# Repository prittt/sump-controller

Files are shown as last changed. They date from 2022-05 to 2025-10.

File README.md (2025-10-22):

# Sump Controller

An basic IoT project to monitor and control the water level in a collecting sump using ESP8266 NodeMCU with email notifications and visual/audio alerts.

<p align="center">
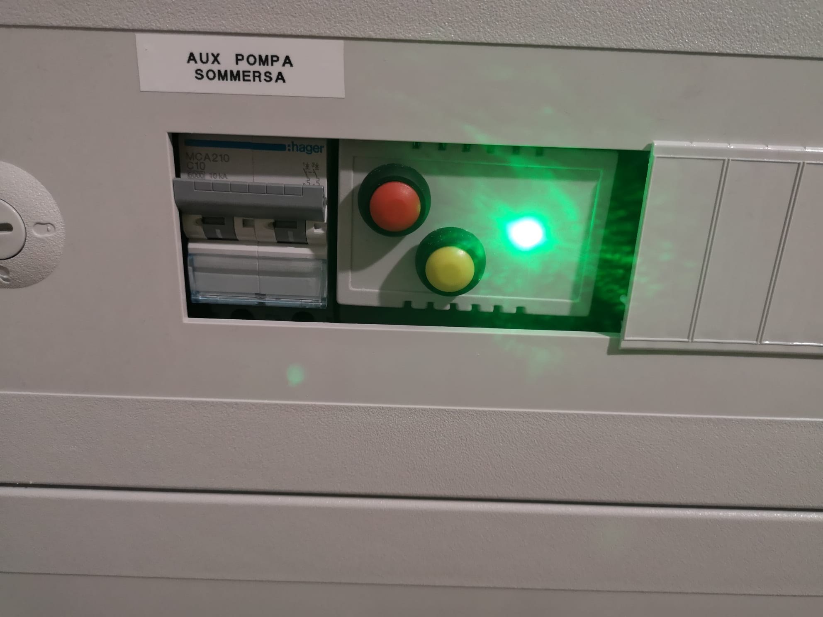
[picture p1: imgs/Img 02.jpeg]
  
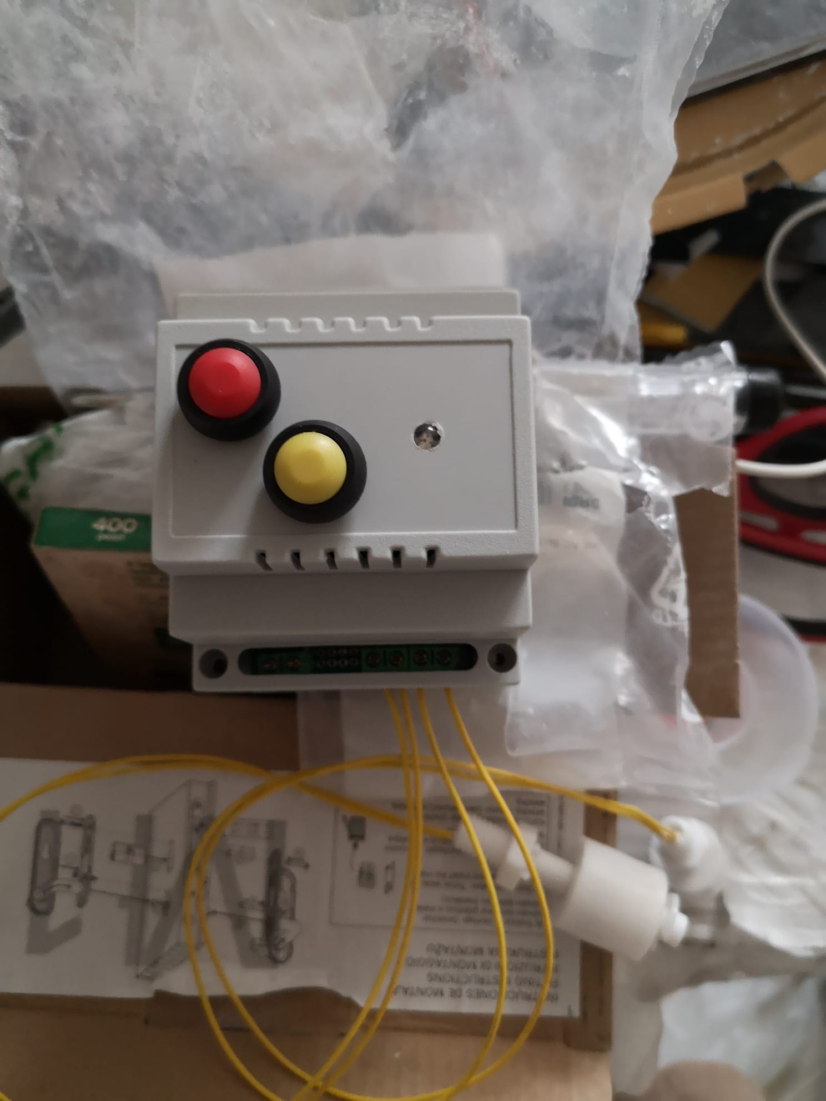
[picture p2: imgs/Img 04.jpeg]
  
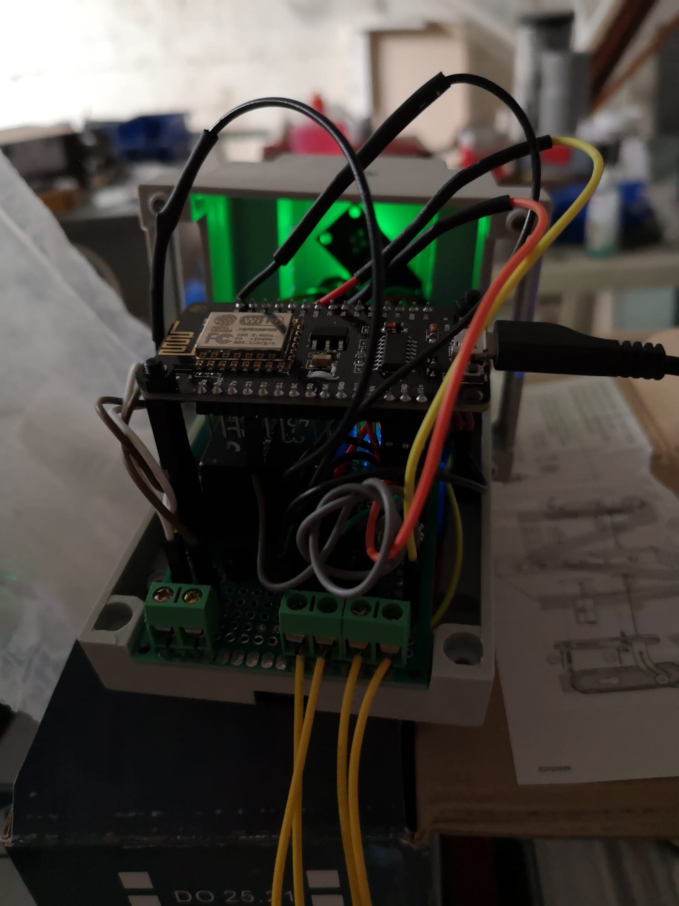
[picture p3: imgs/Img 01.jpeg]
  
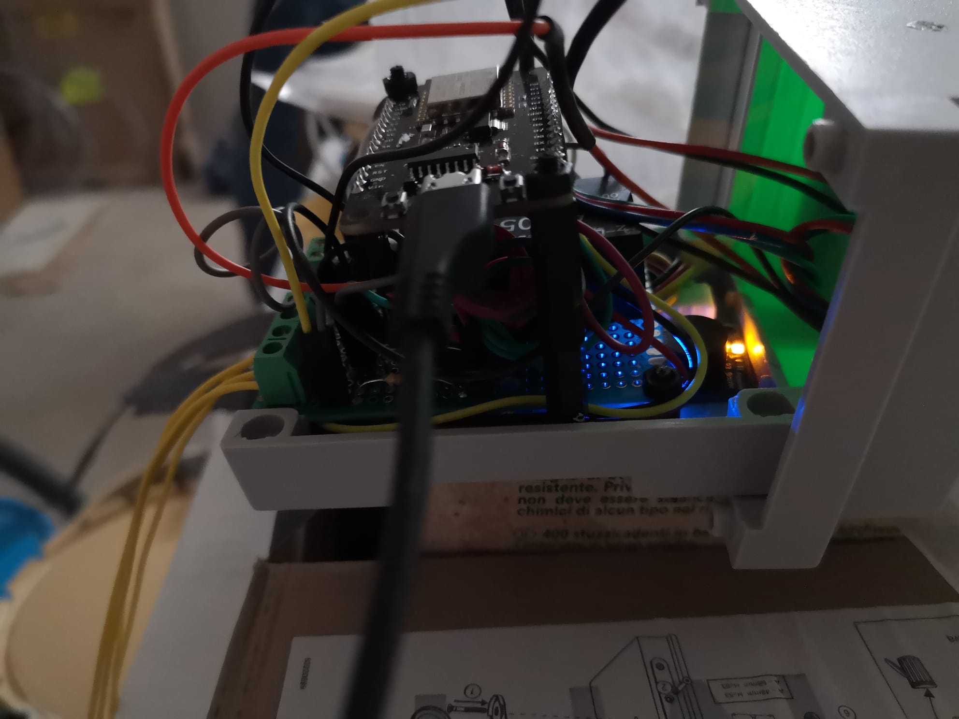
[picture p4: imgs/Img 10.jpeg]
  
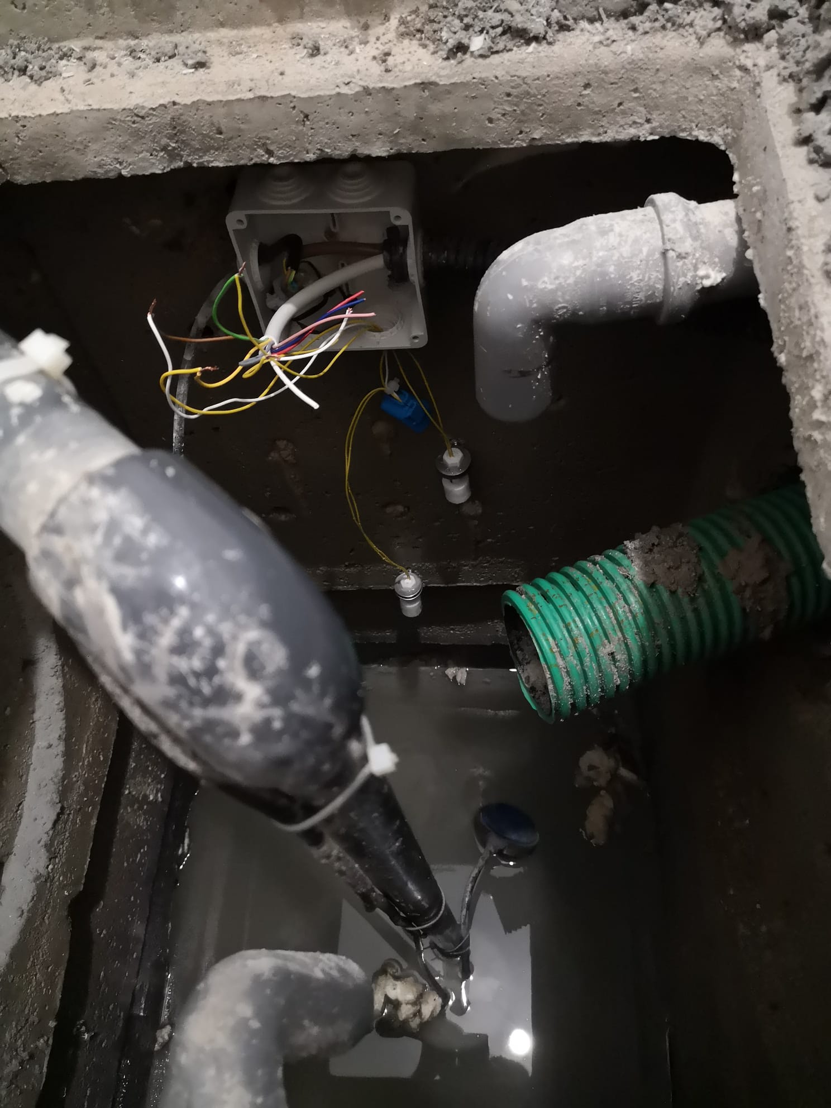
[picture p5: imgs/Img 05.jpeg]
  
</p>

## Overview

This project implements a smart water level monitoring system for sump pumps or water collection basins. The system uses two float switches to detect water levels and provides real-time notifications via email, visual LED indicators, and an audible alarm. The ESP8266 NodeMCU connects to WiFi to send status updates to multiple recipients.

## Features

- **Dual Water Level Detection**: Uses two float switches (low and high) to monitor water levels
- **Email Notifications**: Sends automatic email alerts via Gmail SMTP for different water level conditions:
  - Critical: High water level reached
  - Warning: Low water level reached
  - Restoring: High float deactivated but low float still submerged
  - OK: System returned to normal
  - Weekly checkup: Automatic status email every week
- **Visual Indicators**: RGB LED provides color-coded status:
  - 🟢 Green: Normal operation
  - 🔵 Blue: Warning state
  - 🔴 Red: Critical state
- **Audio Alert**: Buzzer alarm for abnormal water levels with manual disable option
- **Alarm Control**: Additional button to temporarily disable/enable the audio alarm
- **Watchdog Protection**: Prevents ESP8266 crashes during operation

## Hardware Requirements

- ESP8266 NodeMCU development board
- 2x Float switches (low and high water level)
- RGB LED module (common cathode)
- Passive buzzer
- Push button (for alarm control)
- Connecting wires
- Power supply (5V USB or appropriate power source)

## Pin Configuration

| Component | GPIO Pin | NodeMCU Pin |
|---|---|---|
| Low Float Switch | GPIO 12 | D6 |
| High Float Switch | GPIO 13 | D7 |
| Buzzer | GPIO 14 | D5 |
| Red LED | GPIO 5 | D1 |
| Blue LED | GPIO 4 | D2 |
| Green LED | GPIO 16 | D0 |
| Additional Button | GPIO 10 | SD3 |

## Circuit Diagram

The Fritzing schematic is available in the `fritzing/` folder. Additional custom modules used in the design:
- ESP8266 NodeMCU module
- Passive Buzzer module
- RGB Full Color LED module

## Software Dependencies

### Arduino Libraries Required

1. **ESP8266WiFi** - WiFi connectivity for ESP8266
2. **ESP_Mail_Client** - For sending emails via SMTP
3. **aplayer** - Arduino Buzzer Player library from [https://github.com/prittt/ArduinoBuzzerPlayer](https://github.com/prittt/ArduinoBuzzerPlayer)

### Installation

Install the required libraries through the Arduino IDE Library Manager or manually download them from their respective repositories.

## Configuration

### 1. Arduino IDE Setup for ESP8266

Follow the instructions here to enable programming of ESP8266 NodeMCU with Arduino IDE:
[Setting Up the Arduino IDE to Program ESP8266](https://www.instructables.com/Setting-Up-the-Arduino-IDE-to-Program-ESP8266/)

### 2. WiFi Configuration

Edit the following lines in `code/code.ino`:

```cpp
#define WIFI_SSID "your_wifi_ssid"
#define WIFI_PASSWORD "your_wifi_password"
```

### 3. Email Configuration

Configure your Gmail account for SMTP:

```cpp
#define AUTHOR_EMAIL "your_email@gmail.com"
#define AUTHOR_PASSWORD "your_app_password"
```

**Important**: Use an [App Password](https://support.google.com/accounts/answer/185833) instead of your regular Gmail password for security.

Add recipient emails and names:

```cpp
String emails[] = {"recipient1@example.com", "recipient2@example.com"};
size_t emails_size = sizeof(emails)/sizeof(String);
String names[]  = {"Name1", "Name2"};
```

### 4. Timing Configuration

Adjust the following constants as needed:

```cpp
#define STATUS_EMAIL_INTERVAL 604800000  // Weekly status email (in milliseconds)
#define WIFI_CONNECTION_TIMEOUT 15000    // WiFi connection timeout (15 seconds)
#define LOOP_DELAY_NORMAL_MODE 10000     // Normal mode delay (10 seconds)
#define LOOP_DELAY_PROBLEM_MODE 10000    // Problem mode delay (10 seconds)
```

## System States

The system operates in four different states:

1. **FINE (Green LED)**: Both float switches are inactive, water level is normal
2. **WARNING (Blue LED)**: Low float switch is activated, water level is rising
3. **WARNING_RESTORING (Blue LED)**: High float switch deactivated but low float still active
4. **CRITICAL (Red LED)**: High float switch is activated, water level is dangerously high

## Operation

### Normal Operation

1. When powered on, the system connects to WiFi and initializes (Green LED)
2. Continuously monitors both float switches
3. Sends a status email every week to confirm the system is running
4. Changes state and sends notifications when water level changes

### Alarm Control

- Press the additional button briefly to toggle the audio alarm on/off
- When disabled: LED blinks red 3 times
- When enabled: LED blinks green 3 times
- The visual LED status indicator remains active regardless of alarm state

### Email Notifications

The system sends emails for the following events:
- **CRITICAL**: High float switch triggered
- **WARNING**: Low float switch triggered
- **RESTORING?**: Transitioning from critical to warning state
- **OK**: System returned to normal
- **CHECKUP**: Weekly status confirmation (sent every 7 days)

## Debug Mode

To enable serial debug output, set:

```cpp
#define DEBUG true
```

This will print detailed status information to the Serial Monitor at 115200 baud.

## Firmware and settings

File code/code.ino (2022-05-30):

#include <aplayer.h> // Code from https://github.com/prittt/ArduinoBuzzerPlayer

#define DEBUG false

#include <Arduino.h>
#include <aplayer.h>

#if defined(ESP32)
  #include <WiFi.h>
#elif defined(ESP8266)
  #include <ESP8266WiFi.h>
#endif
#include <ESP_Mail_Client.h>

//#define WIFI_SSID "HUAWEI P20"
//#define WIFI_PASSWORD "123456789"
#define WIFI_SSID "welcometothejungle"
#define WIFI_PASSWORD "W!ldB&&r52"

#define SMTP_HOST "smtp.gmail.com"
#define SMTP_PORT 465

/* The sign in credentials */
#define AUTHOR_EMAIL "pozzetto.firenze@gmail.com"
#define AUTHOR_PASSWORD "ibqjxrdfflnfwngy"

/* Recipient's emails and names*/
String emails[] = {"federico.bolelli@unimore.it", "elena.bega.mo@gmail.com"};
size_t emails_size = sizeof(emails)/sizeof(String);
String names[]  = {"Federico", "Elena"};

#define FLOATINGLOW_PIN   12 // Pin connected to the lower floating
#define FLOATINGHIGHT_PIN 13 // Pin connected to the higher floating
#define BUZZER_PIN        14 // Pin which control the buzzer
APlayer myPlayer(BUZZER_PIN); // Create a player object specifying the buzzer's pin

#define GREENLED_PIN 16 // Pin to control green LED
#define REDLED_PIN    5 // Pin to control red LED
#define BLUELED_PIN   4 // Pin to control yellow LED

#define STATUS_EMAIL_INTERVAL 604800000 // One week
unsigned long int last_email_sent = millis() - STATUS_EMAIL_INTERVAL; // This is to ensure that the email will be sent at startup

#define WIFI_CONNECTION_TIMEOUT 15000  // 15s // 30000 // 30s
#define LOOP_DELAY_NORMAL_MODE  10000  // 10s // 300000 // 5m
#define LOOP_DELAY_PROBLEM_MODE 10000  // 10s 

#define ADDITIONAL_BUTTON 10

/* The SMTP Session object used for Email sending */
SMTPSession smtp;

// Butto press function with "debouncing"
# define BUTTONS_PRESS_TIME_SHORT 1000
# define BUTTONS_PRESS_TIME_LONG 3000
bool IsPressed(int button_pin, unsigned long press_duration = BUTTONS_PRESS_TIME_SHORT, bool direct = 1){
    
    if (!direct){
        if(digitalRead(button_pin) == LOW){
          unsigned long start_press = millis();
          while(digitalRead(button_pin) == LOW && (millis() - start_press < press_duration)){wdt_reset();} // The reset on the ESP8266 must be fast (watchdog max-time is quite small). The call to wdt_reset() is to avoid the random crash of the module!
  
          if(digitalRead(button_pin) == LOW && (millis() - start_press >= press_duration)){
            return true;  
          }
        }
    }else{
        if(digitalRead(button_pin) == HIGH){
          unsigned long start_press = millis();
          while(digitalRead(button_pin) == HIGH && (millis() - start_press < press_duration)){wdt_reset();} // The reset on the ESP8266 must be fast (watchdog max-time is quite small). The call to wdt_reset() is to avoid the random crash of the module!
  
          if(digitalRead(button_pin) == HIGH && (millis() - start_press >= press_duration)){
            return true;  
          }
        }
    }
    
    return false;
}

/* Callback function to get the Email sending status */
void smtpCallback(SMTP_Status status);

bool ConnectToWifiAndSendEmail(String floating_status, String email_content){
  if (DEBUG){
    Serial.println();
    Serial.print("Connecting to AP");
  }
  
  WiFi.begin(WIFI_SSID, WIFI_PASSWORD);
  unsigned long connection_start = millis();
  while (WiFi.status() != WL_CONNECTED){
    if (millis() - connection_start > WIFI_CONNECTION_TIMEOUT) {

        if (DEBUG){
          Serial.println("Unable to connect to the WiFi, skipping");
        }
      return false;  
    }
    
    if (DEBUG){
      Serial.print(".");
    }
    delay(200);
  }

  if (DEBUG){
    Serial.println("");
    Serial.println("WiFi connected.");
    Serial.println("IP address: ");
    Serial.println(WiFi.localIP());
    Serial.println();
  }
  
  /** Enable the debug via Serial port
   * none debug or 0
   * basic debug or 1
  */
  smtp.debug(DEBUG);

  /* Set the callback function to get the sending results */
  smtp.callback(smtpCallback);

  /* Declare the session config data */
  ESP_Mail_Session session;

  /* Set the session config */
  session.server.host_name = SMTP_HOST;
  session.server.port = SMTP_PORT;
  session.login.email = AUTHOR_EMAIL;
  session.login.password = AUTHOR_PASSWORD;
  session.login.user_domain = "";

  /* Declare the message class */
  SMTP_Message message;

  /* Set the message headers */
  message.sender.name = "Pozzetto Via Firenze";
  message.sender.email = AUTHOR_EMAIL;
  message.subject = floating_status;

  for (size_t i = 0; i < emails_size; ++i) {
    message.addRecipient(names[i], emails[i]);
  }

  /*Send HTML message*/
  String htmlMsg = "<h1>" + email_content + "</h1><p>Sent from ESP board</p>";
  message.html.content = htmlMsg.c_str();
  message.html.content = htmlMsg.c_str();
  message.text.charSet = "us-ascii";
  message.html.transfer_encoding = Content_Transfer_Encoding::enc_7bit;

  /*
  //Send raw text message
  String textMsg = "Hello World! - Sent from ESP board";
  message.text.content = textMsg.c_str();
  message.text.charSet = "us-ascii";
  message.text.transfer_encoding = Content_Transfer_Encoding::enc_7bit;
  
  message.priority = esp_mail_smtp_priority::esp_mail_smtp_priority_low;
  message.response.notify = esp_mail_smtp_notify_success | esp_mail_smtp_notify_failure | esp_mail_smtp_notify_delay;*/

  /* Set the custom message header */
  //message.addHeader("Message-ID: <abcde.fghij@gmail.com>");

  /* Connect to server with the session config */
  if (!smtp.connect(&session)){
    return false;
  }

  /* Start sending Email and close the session */
  if (!MailClient.sendMail(&smtp, &message)){
    return false;
    if (DEBUG){ 
      Serial.println("Error sending Email, " + smtp.errorReason());
    }
  }
  return true;
}

void SetBlue(){
  analogWrite(BLUELED_PIN , 255);
  analogWrite(REDLED_PIN  , 0);
  analogWrite(GREENLED_PIN, 0);   
}

void SetRed(){
  analogWrite(BLUELED_PIN , 0);
  analogWrite(REDLED_PIN  , 255);
  analogWrite(GREENLED_PIN, 0);   
}

void SetGreen(){
  analogWrite(BLUELED_PIN , 0);
  analogWrite(REDLED_PIN  , 0);
  analogWrite(GREENLED_PIN, 255);   
}

void setup(){
  pinMode(FLOATINGLOW_PIN  , INPUT);
  pinMode(FLOATINGHIGHT_PIN, INPUT);

  pinMode(ADDITIONAL_BUTTON, INPUT);

  pinMode(BLUELED_PIN, OUTPUT);
  pinMode(REDLED_PIN , OUTPUT);
  pinMode(BLUELED_PIN, OUTPUT);

  SetGreen();

  if (DEBUG){
    Serial.begin(115200);
  }
}

enum system_status {
  FINE = 0, 
  WARNING = 1,
  WARNING_RESTORING = 2,
  CRITICAL = 3
};

int current_status = FINE;
int last_email_succesfully_sent = true;

void SetOff() {
  analogWrite(BLUELED_PIN , 0);
  analogWrite(REDLED_PIN  , 0);
  analogWrite(GREENLED_PIN, 0);   
}

void BlinkRed(int n = 3, int freq = 100) {
  for (int i = 0; i < n; ++i) {
    SetRed();
    delay(freq);
    SetOff();
    delay(freq);  
  }
}

void BlinkGreen(int n = 3, int freq = 100) {
  for (int i = 0; i < n; ++i) {
    SetGreen();
    delay(freq);
    SetOff();
    delay(freq);  
  }
}

bool alarm_disabled = false;

void loop(){

  bool hight_floating_pressed = IsPressed(FLOATINGHIGHT_PIN);
  bool   low_floating_pressed = IsPressed(FLOATINGLOW_PIN);
  bool   additional_button    = IsPressed(ADDITIONAL_BUTTON, BUTTONS_PRESS_TIME_SHORT, 0);

  if (DEBUG) {
    Serial.println("");
    Serial.print("hight_floating_pressed = "); hight_floating_pressed ? Serial.println("true") : Serial.println("false");
    Serial.print("low_floating_pressed = ");   low_floating_pressed   ? Serial.println("true") : Serial.println("false");
    Serial.print("additional_button = ");      additional_button      ? Serial.println("true") : Serial.println("false");
    Serial.print("STATUS "); Serial.print(current_status);
  }

  if (additional_button) {
      alarm_disabled = !alarm_disabled;
      if (DEBUG){
        Serial.println("");
        Serial.print("Change alarm status to "); !alarm_disabled ? Serial.println("true") : Serial.println("false");
      }        
      if (alarm_disabled) {
        BlinkRed();  
      } else {
        BlinkGreen();  
      }

       switch(current_status) {
        case FINE: SetGreen(); break;
        case WARNING_RESTORING: 
        case WARNING: SetBlue(); break;
        case CRITICAL: SetRed(); break;
      }
  }

  if (millis() - last_email_sent > STATUS_EMAIL_INTERVAL) {
      ConnectToWifiAndSendEmail("CHECKUP", "Il sitema è up and running!");
      last_email_sent = millis();
  }

  if (current_status != FINE && !alarm_disabled) {
      myPlayer.play(ALARM);
  }

  if (!last_email_succesfully_sent) {
      switch(current_status) {
        case FINE: last_email_succesfully_sent = ConnectToWifiAndSendEmail("OK", "Tutto è tornato alla normalità."); break;
        case WARNING_RESTORING: last_email_succesfully_sent = ConnectToWifiAndSendEmail("RESTORING?", "Il galleggiante alto è disattivo, ma quello basso è ancora sommerso!"); break;
        case WARNING: last_email_succesfully_sent = ConnectToWifiAndSendEmail("WARNING", "Il galleggiante basso è scattato!"); break;
        case CRITICAL: last_email_succesfully_sent = ConnectToWifiAndSendEmail("CRITICAL", "Il galleggiante alto è scattato!"); break;
      }
  }


  // Check the higher floating 
  if (hight_floating_pressed && current_status != CRITICAL){   
    current_status = CRITICAL; // Update the current status

    /* Change LED status: RED */
    SetRed();

    last_email_succesfully_sent = ConnectToWifiAndSendEmail("CRITICAL", "Il galleggiante alto è scattato!");
  } 
  
  if (low_floating_pressed && !hight_floating_pressed && current_status != WARNING && current_status != WARNING_RESTORING){   
    /* Change LED status: RED */
    SetBlue();

    if (current_status == FINE){
      if (DEBUG){
        Serial.println(".");
      }
      last_email_succesfully_sent = ConnectToWifiAndSendEmail("WARNING", "Il galleggiante basso è scattato!");
      current_status = WARNING; // Update the current status
    } else {
      /* Current status is CRTICAL*/
      last_email_succesfully_sent = ConnectToWifiAndSendEmail("RESTORING?", "Il galleggiante alto è disattivo, ma quello basso è ancora sommerso!");
      current_status = WARNING_RESTORING; // Update the current status
    }
     
  }
  
  if (current_status != FINE && !low_floating_pressed && !hight_floating_pressed /* This second check should be useless, but I'll leave to "cope" with a broken lower floating */){  
    current_status = FINE; // Update the current status

    /* Change LED status: GREEN;*/
    SetGreen();

    last_email_succesfully_sent = ConnectToWifiAndSendEmail("OK", "Tutto è tornato alla normalità.");
  } 
  if (current_status == FINE){
    delay(LOOP_DELAY_NORMAL_MODE);
  } else {
    delay(LOOP_DELAY_PROBLEM_MODE);
  }
}

/* Callback function to get the Email sending status */
void smtpCallback(SMTP_Status status){
  /* Print the current status */
  Serial.println(status.info());

  /* Print the sending result */
  if (status.success()){
    Serial.println("----------------");
    ESP_MAIL_PRINTF("Message sent success: %d\n", status.completedCount());
    ESP_MAIL_PRINTF("Message sent failled: %d\n", status.failedCount());
    Serial.println("----------------\n");
    struct tm dt;

    for (size_t i = 0; i < smtp.sendingResult.size(); i++){
      /* Get the result item */
      SMTP_Result result = smtp.sendingResult.getItem(i);
      time_t ts = (time_t)result.timestamp;
      localtime_r(&ts, &dt);

      ESP_MAIL_PRINTF("Message No: %d\n", i + 1);
      ESP_MAIL_PRINTF("Status: %s\n", result.completed ? "success" : "failed");
      ESP_MAIL_PRINTF("Date/Time: %d/%d/%d %d:%d:%d\n", dt.tm_year + 1900, dt.tm_mon + 1, dt.tm_mday, dt.tm_hour, dt.tm_min, dt.tm_sec);
      ESP_MAIL_PRINTF("Recipient: %s\n", result.recipients);
      ESP_MAIL_PRINTF("Subject: %s\n", result.subject);
    }
    Serial.println("----------------\n");
  }
}
